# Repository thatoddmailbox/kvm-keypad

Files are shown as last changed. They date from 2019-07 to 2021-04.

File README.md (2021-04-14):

# kvm-keypad


The keypad for the [open-source HDMI KVM switch I built](https://github.com/thatoddmailbox/kvm#kvm). It's a 3x3 array of buttons, allowing you to decide where monitor 1, monitor 2, and the USB devices are routed to.

It connects via a PS/2 cable to [kvm-base](https://github.com/thatoddmailbox/kvm-base#kvm-base)&mdash;however, it does _not_ use the actual PS/2 protocol.

## Useful links
* [Rev A schematic](./mfg/revA/kvm-keypad.pdf)
* [Rev A BOM](./mfg/revA/kvm-keypad.csv)

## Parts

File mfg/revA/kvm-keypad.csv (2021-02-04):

Reference | Value | Footprint | Datasheet
J2 | Mini-DIN-6 | kvm-keypad:PS2 | http://service.powerdynamics.com/ec/Catalog17/Section%2011.pdf
U1 | STM8S003F3P | Package_SO:TSSOP-20_4.4x6.5mm_P0.65mm | http://www.st.com/st-web-ui/static/active/en/resource/technical/document/datasheet/DM00024550.pdf
U3 | IS31FL3218 | Package_SO:SOIC-24W_7.5x15.4mm_P1.27mm
C3 | 0.1uF | Capacitor_SMD:C_0603_1608Metric_Pad1.05x0.95mm_HandSolder | ~
U2 | PCAL6416A | Package_SO:TSSOP-24_4.4x7.8mm_P0.65mm
C4 | 0.1uF | Capacitor_SMD:C_0603_1608Metric_Pad1.05x0.95mm_HandSolder | ~
C2 | 0.1uF | Capacitor_SMD:C_0603_1608Metric_Pad1.05x0.95mm_HandSolder | ~
SW2 | A1 | kvm-keypad:K6-1212A | ~
SW5 | A2 | kvm-keypad:K6-1212A | ~
SW8 | A3 | kvm-keypad:K6-1212A | ~
SW10 | C3 | kvm-keypad:K6-1212A | ~
SW7 | C2 | kvm-keypad:K6-1212A | ~
SW4 | C1 | kvm-keypad:K6-1212A | ~
SW9 | B3 | kvm-keypad:K6-1212A | ~
SW6 | B2 | kvm-keypad:K6-1212A | ~
SW3 | B1 | kvm-keypad:K6-1212A | ~
R3 | 3.3k | Resistor_SMD:R_0603_1608Metric_Pad1.05x0.95mm_HandSolder | ~
J1 | Debug | Connector_PinSocket_2.54mm:PinSocket_2x04_P2.54mm_Vertical | ~
C1 | 0.47uF | Capacitor_SMD:C_0603_1608Metric_Pad1.05x0.95mm_HandSolder | ~
SW1 | Reset | Button_Switch_SMD:SW_Push_1P1T_NO_6x6mm_H9.5mm | ~
R2 | 10k | Resistor_SMD:R_0603_1608Metric_Pad1.05x0.95mm_HandSolder | ~
R1 | 10k | Resistor_SMD:R_0603_1608Metric_Pad1.05x0.95mm_HandSolder | ~

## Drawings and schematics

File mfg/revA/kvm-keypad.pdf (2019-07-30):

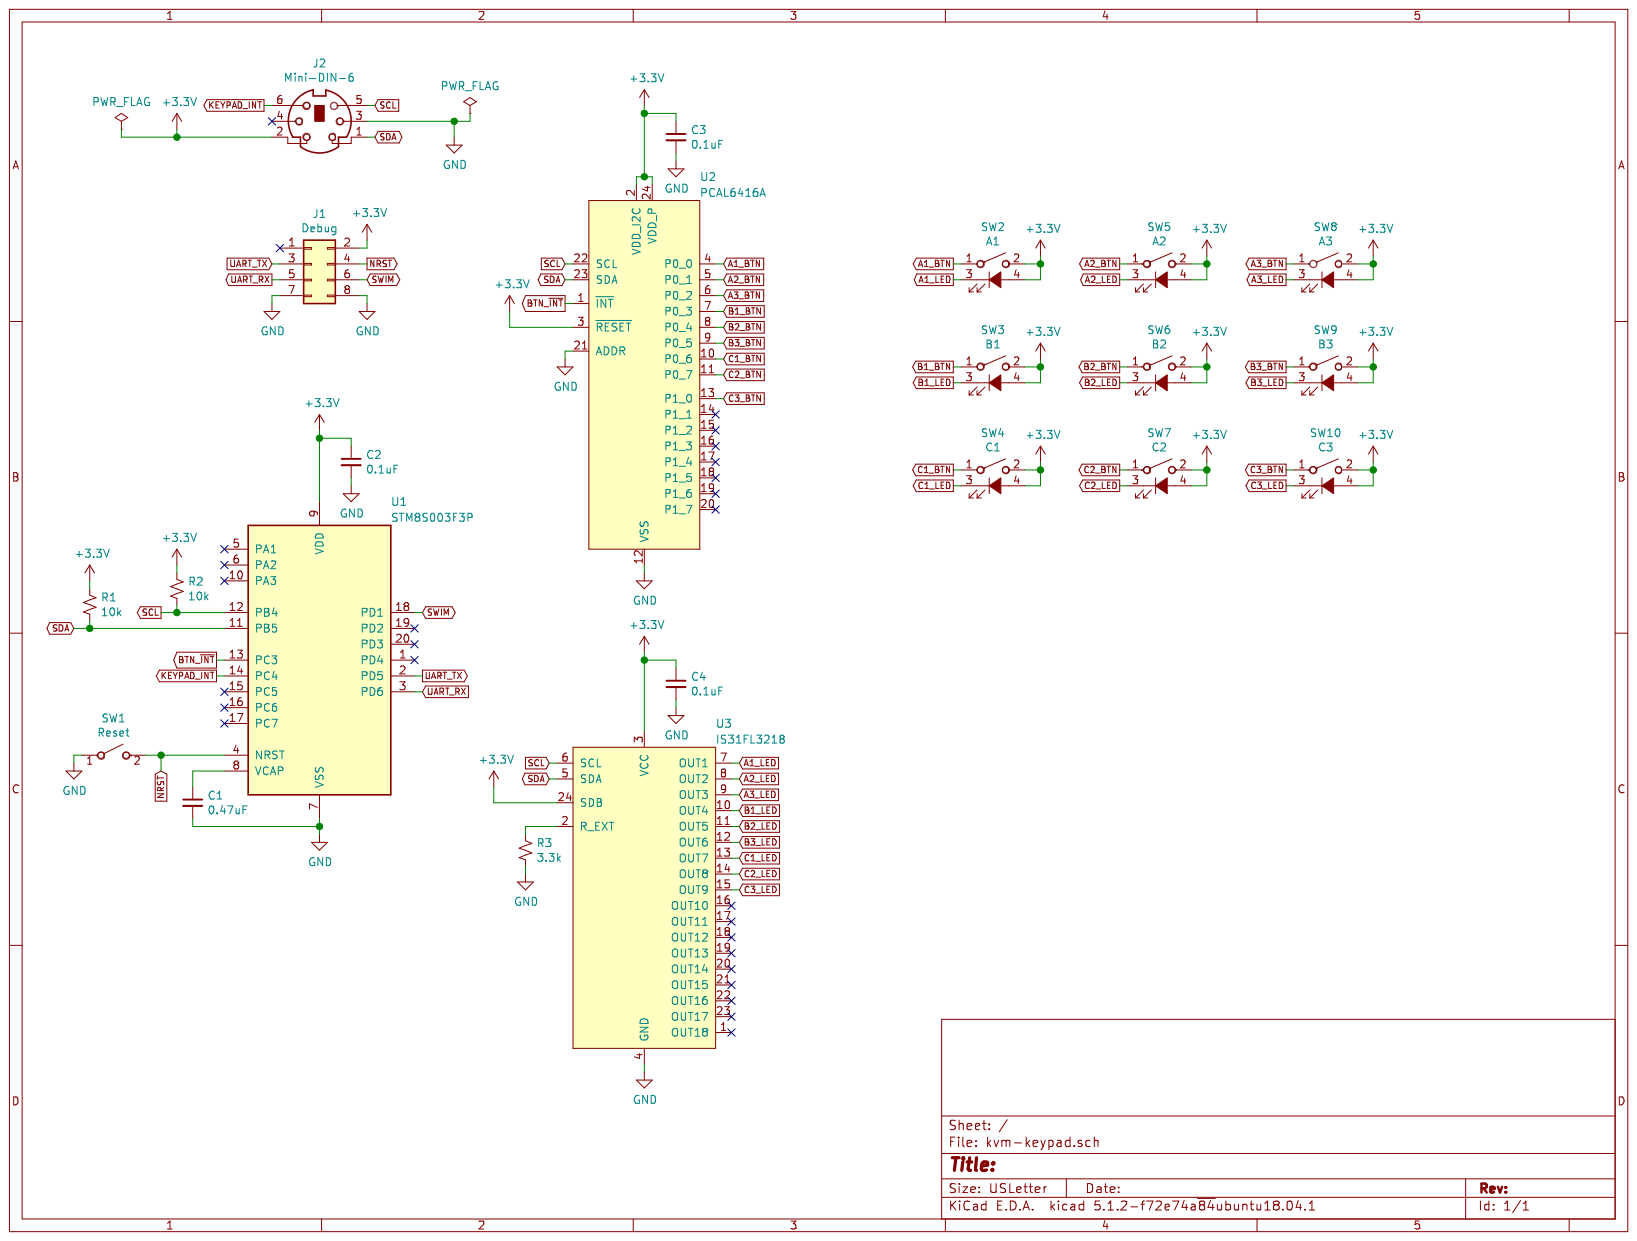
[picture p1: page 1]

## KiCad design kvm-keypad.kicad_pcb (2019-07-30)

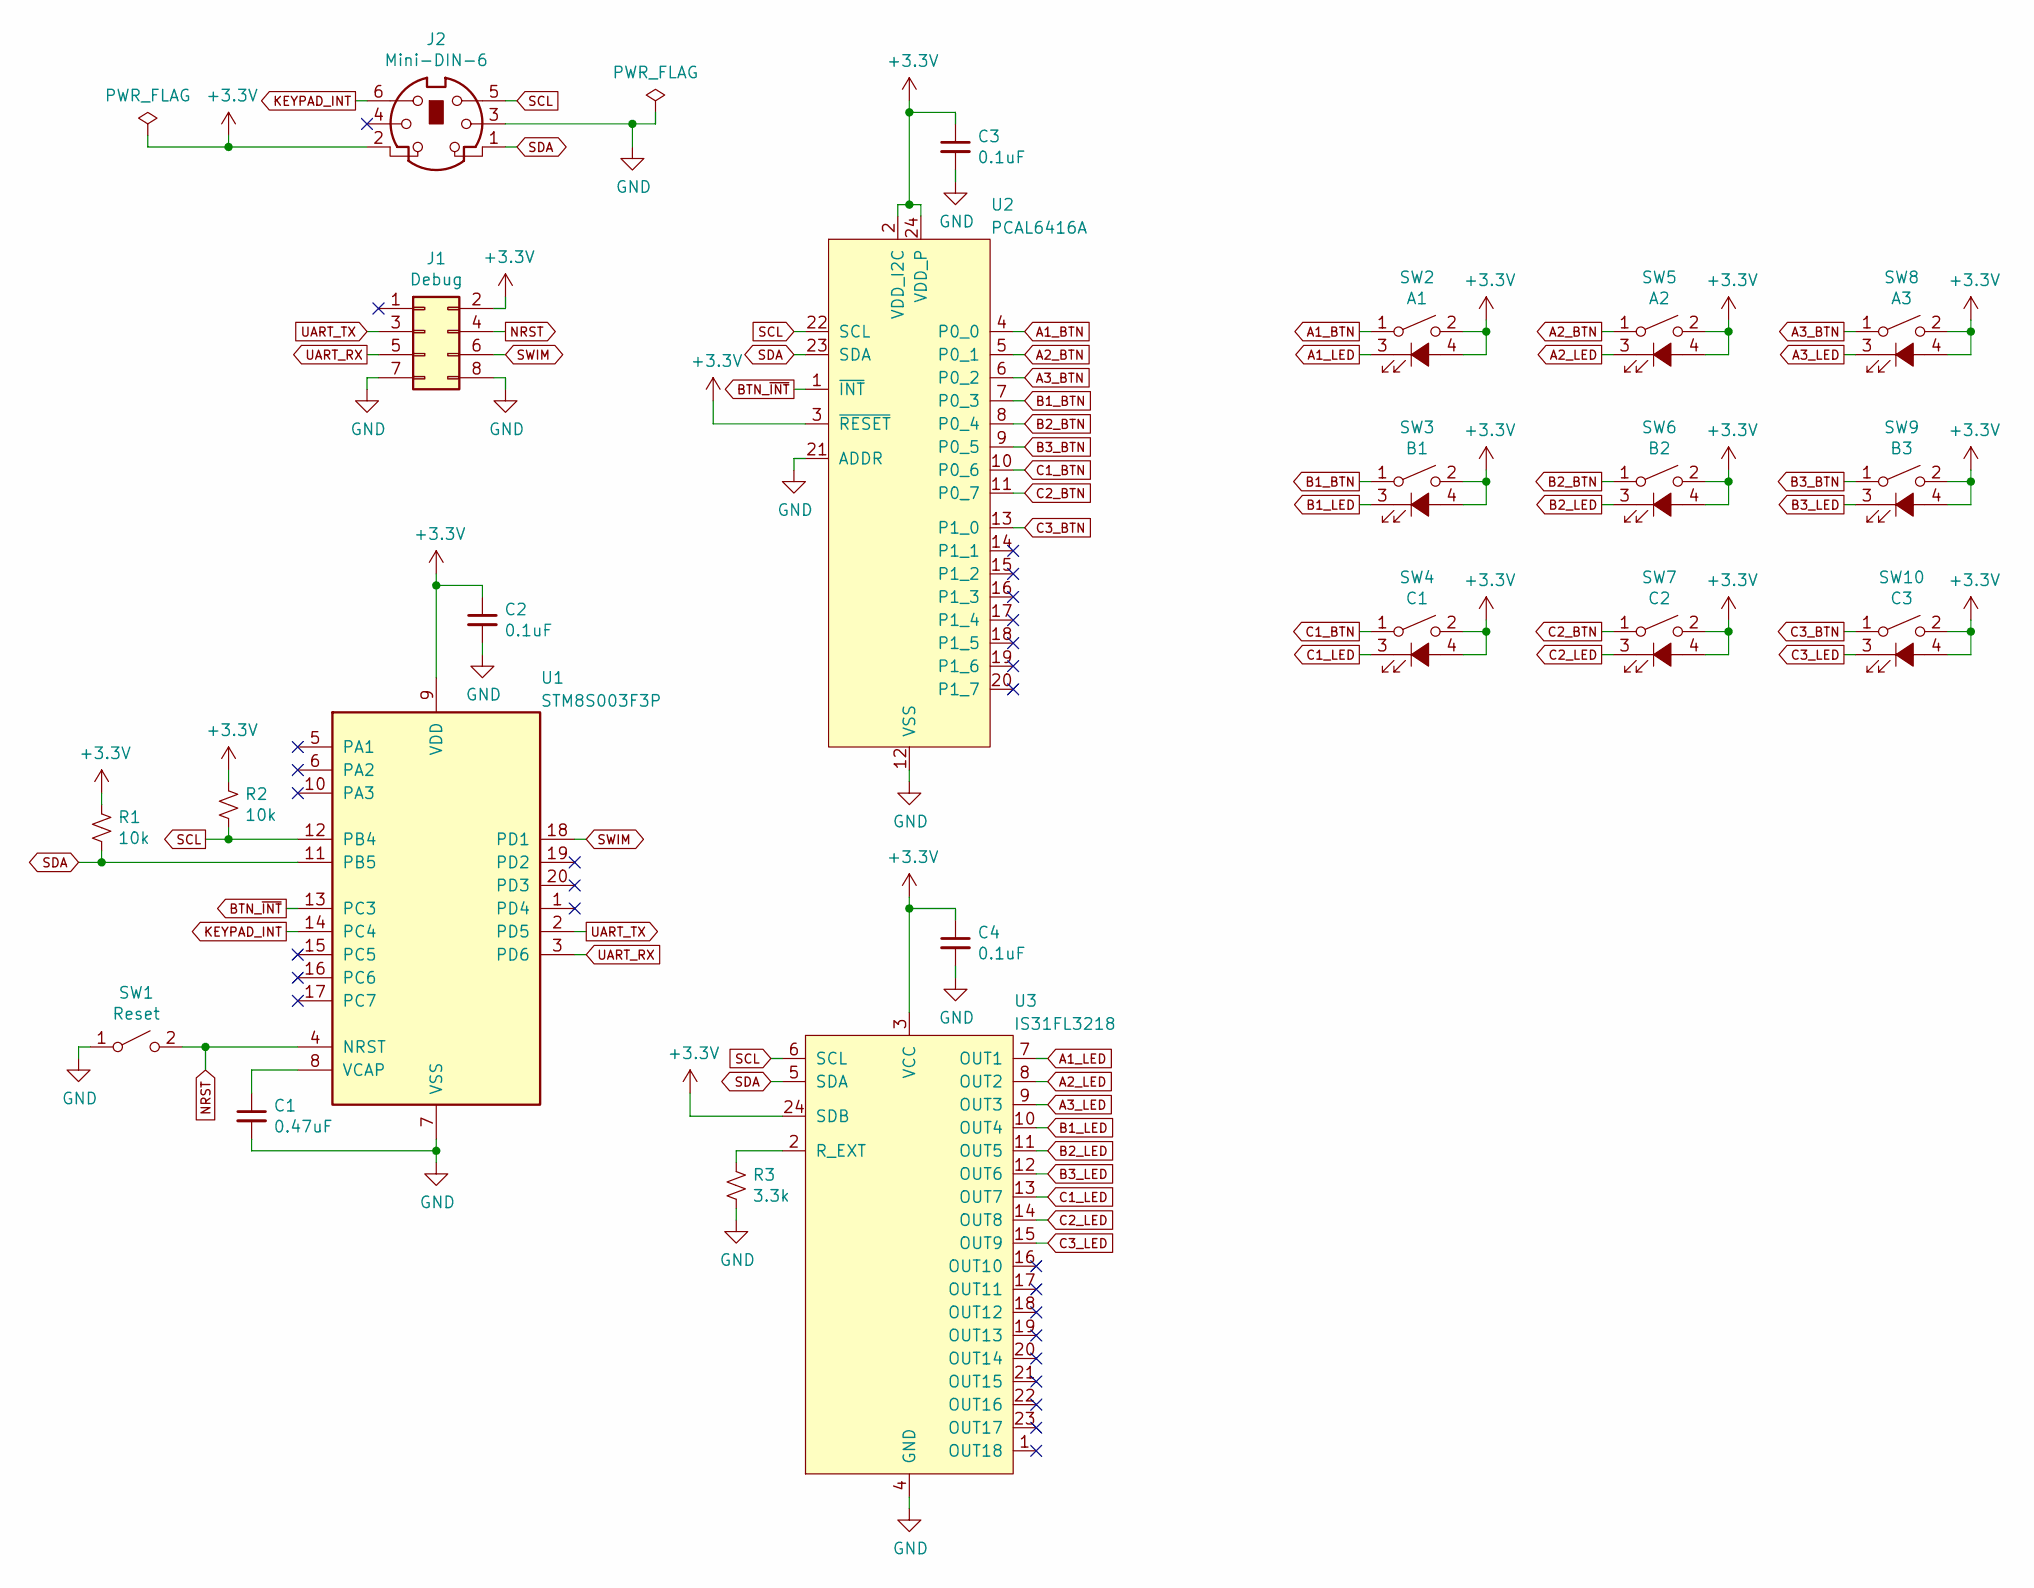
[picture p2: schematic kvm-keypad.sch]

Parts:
C1: 0.47uF; C_0603_1608Metric_Pad1.05x0.95mm_HandSolder
C2, C3, C4: 0.1uF; C_0603_1608Metric_Pad1.05x0.95mm_HandSolder
J1: Debug; PinSocket_2x04_P2.54mm_Vertical
J2: Mini-DIN-6; PS2
R1, R2: 10k; R_0603_1608Metric_Pad1.05x0.95mm_HandSolder
R3: 3.3k; R_0603_1608Metric_Pad1.05x0.95mm_HandSolder
SW1: Reset; SW_Push_1P1T_NO_6x6mm_H9.5mm
SW2: A1; K6-1212A
SW3: B1; K6-1212A
SW4: C1; K6-1212A
SW5: A2; K6-1212A
SW6: B2; K6-1212A
SW7: C2; K6-1212A
SW8: A3; K6-1212A
SW9: B3; K6-1212A
SW10: C3; K6-1212A
U1: STM8S003F3P; TSSOP-20_4.4x6.5mm_P0.65mm
U2: PCAL6416A; TSSOP-24_4.4x7.8mm_P0.65mm
U3: IS31FL3218; SOIC-24W_7.5x15.4mm_P1.27mm

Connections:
+3V3: C2.1, C3.1, C4.1, J1.2, J2.2, R1.1, R2.1, SW2.2, SW2.4 (A), SW3.2, SW3.4 (A), SW4.2, SW4.4 (A), SW5.2, SW5.4 (A), SW6.2, SW6.4 (A), SW7.2, SW7.4 (A), SW8.2, SW8.4 (A), SW9.2, SW9.4 (A), SW10.2, SW10.4 (A), U1.9 (VDD), U2.2 (VDD_I2C), U2.3 (~RESET), U2.24 (VDD_P), U3.3 (VCC), U3.24 (SDB)
A1_BTN: SW2.1, U2.4 (P0_0)
A1_LED: SW2.3 (K), U3.7 (OUT1)
A2_BTN: SW5.1, U2.5 (P0_1)
A2_LED: SW5.3 (K), U3.8 (OUT2)
A3_BTN: SW8.1, U2.6 (P0_2)
A3_LED: SW8.3 (K), U3.9 (OUT3)
B1_BTN: SW3.1, U2.7 (P0_3)
B1_LED: SW3.3 (K), U3.10 (OUT4)
B2_BTN: SW6.1, U2.8 (P0_4)
B2_LED: SW6.3 (K), U3.11 (OUT5)
B3_BTN: SW9.1, U2.9 (P0_5)
B3_LED: SW9.3 (K), U3.12 (OUT6)
BTN_~INT: U1.13 (PC3), U2.1 (~INT)
C1_BTN: SW4.1, U2.10 (P0_6)
C1_LED: SW4.3 (K), U3.13 (OUT7)
C2_BTN: SW7.1, U2.11 (P0_7)
C2_LED: SW7.3 (K), U3.14 (OUT8)
C3_BTN: SW10.1, U2.13 (P1_0)
C3_LED: SW10.3 (K), U3.15 (OUT9)
GND: C1.2, C2.2, C3.2, C4.2, J1.7, J1.8, J2.3, R3.2, SW1.1 (A), U1.7 (VSS), U2.12 (VSS), U2.21 (ADDR), U3.4 (GND)
KEYPAD_INT: J2.6, U1.14 (PC4)
NRST: J1.4, SW1.2 (B), U1.4 (NRST)
unnamed: C1.1, U1.8 (VCAP)
unnamed: R3.1, U3.2 (R_EXT)
SCL: J2.5, R2.2, U1.12 (PB4), U2.22 (SCL), U3.6 (SCL)
SDA: J2.1, R1.2, U1.11 (PB5), U2.23 (SDA), U3.5 (SDA)
SWIM: J1.6, U1.18 (PD1)
UART_RX: J1.5, U1.3 (PD6)
UART_TX: J1.3, U1.2 (PD5)

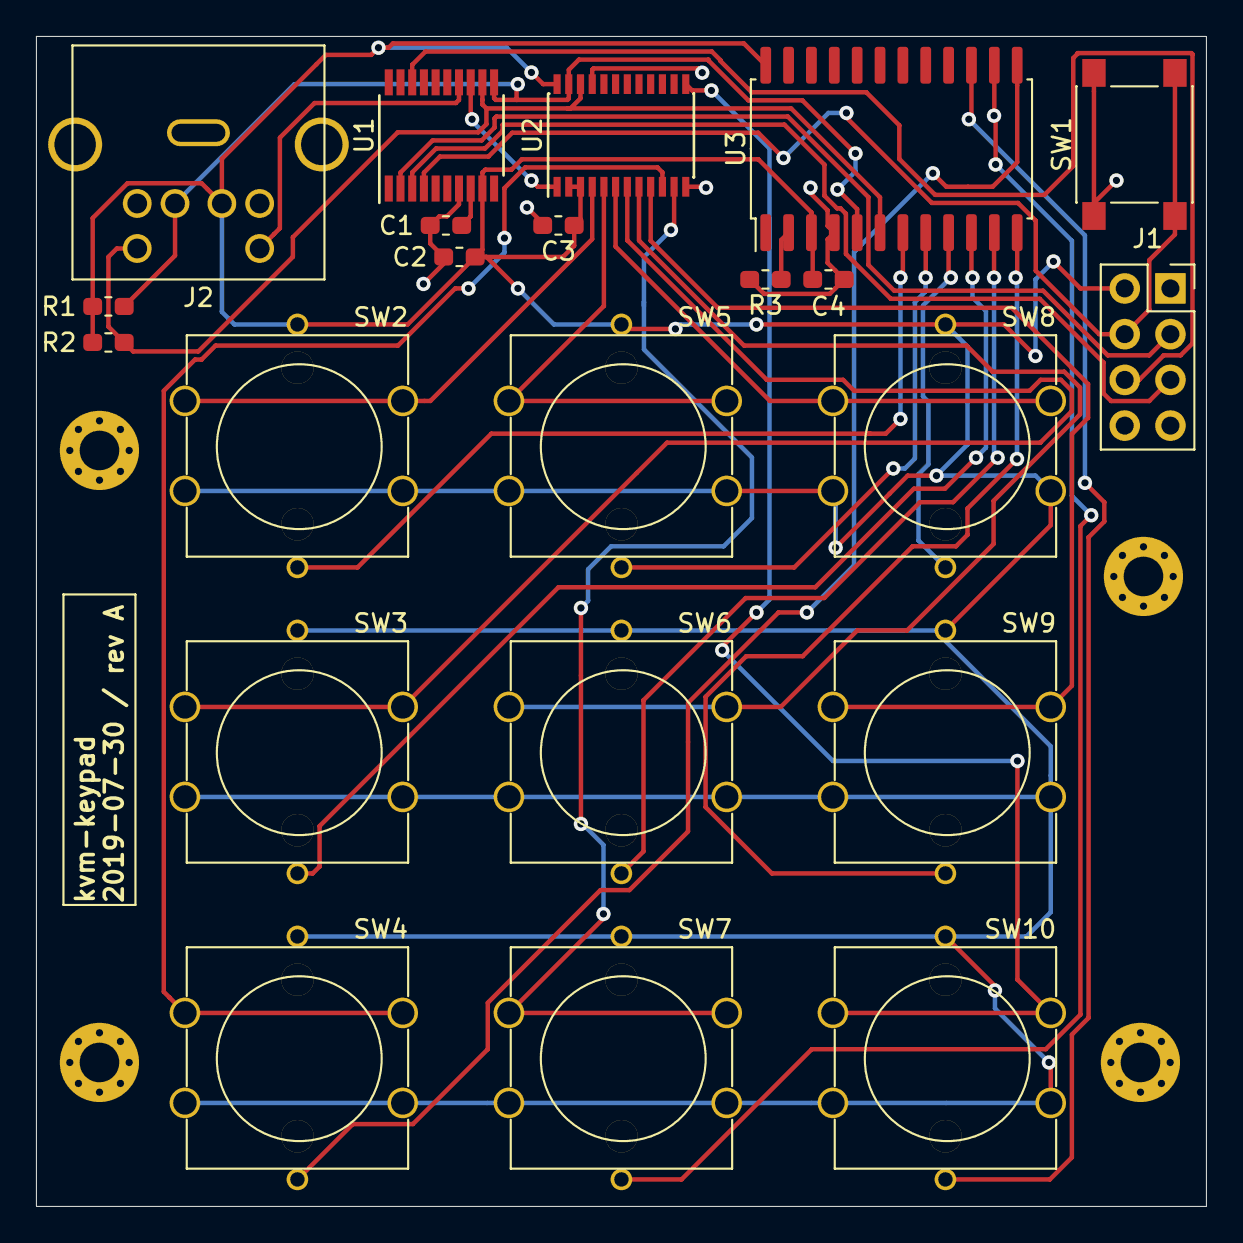
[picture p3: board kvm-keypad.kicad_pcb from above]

Board: 2 copper layers, 65.0 x 65.0 mm, 22 parts (0 on the bottom side), 30 nets.

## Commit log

2019-07-30 commit rev A schematic, pcb, and gerbers
    [kvm-keypad-B_Cu.gbr, kvm-keypad-B_Mask.gbr, kvm-keypad-B_Paste.gbr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]
2021-02-04 readme: add note about ps/2 cable
2021-02-04 add csv bom file for rev A
    [kvm-keypad.csv]
2021-02-04 readme: add links to schematic and bom
